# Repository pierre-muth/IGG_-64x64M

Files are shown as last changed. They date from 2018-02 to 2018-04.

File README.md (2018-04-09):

# IGG_-64x64M
Driving and use the ИГГ1/64x64M. Gazotron Dot-matrix display made in Ukraine in the 80's
Details: https://hackaday.io/project/46302-1-64x64m-adventure

Status:
High voltage (360v from 180v) driver circuit board
PIC 18F87K90 serial interface

Connected to a raspberry-pi: https://youtu.be/ZqoKS0ZieYE 





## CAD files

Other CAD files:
pic/igg_driver_test_01.X/dist/default/production/igg_driver_test_01.X.production.obj

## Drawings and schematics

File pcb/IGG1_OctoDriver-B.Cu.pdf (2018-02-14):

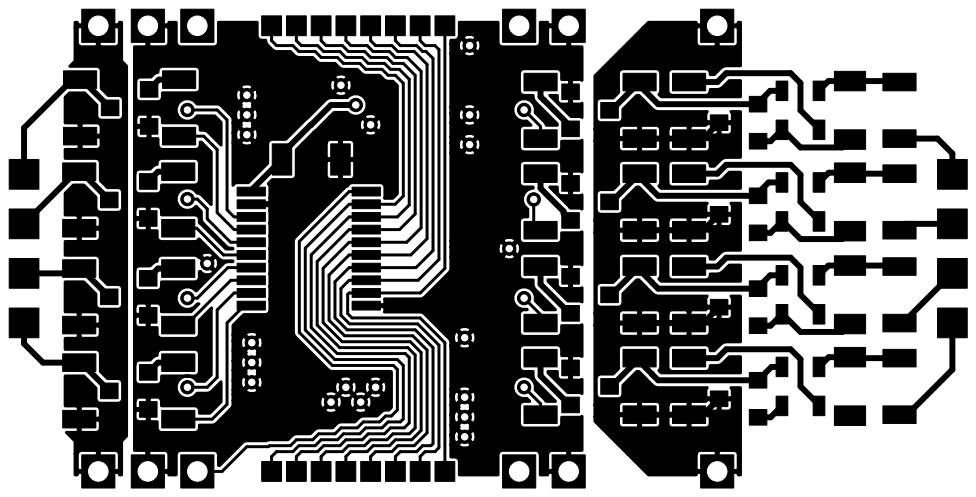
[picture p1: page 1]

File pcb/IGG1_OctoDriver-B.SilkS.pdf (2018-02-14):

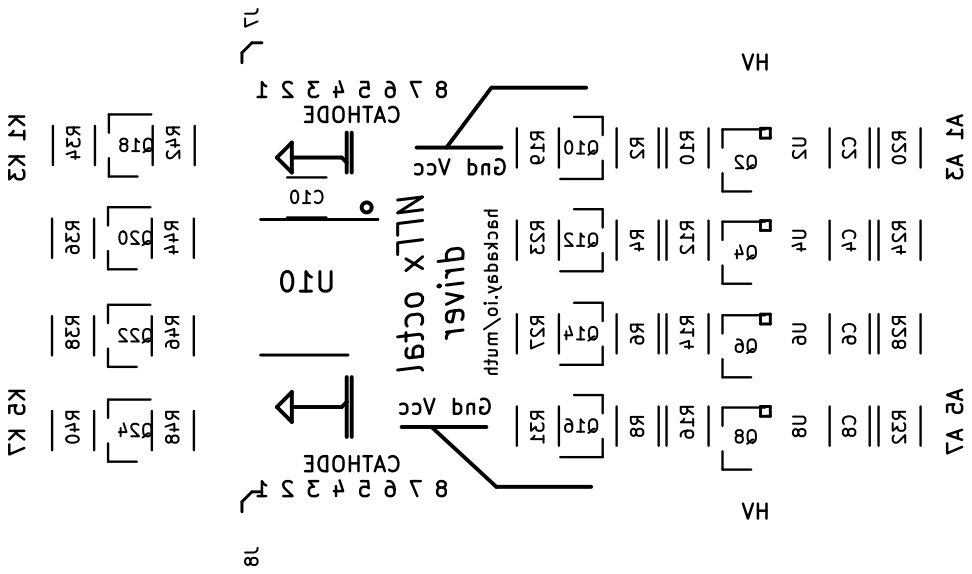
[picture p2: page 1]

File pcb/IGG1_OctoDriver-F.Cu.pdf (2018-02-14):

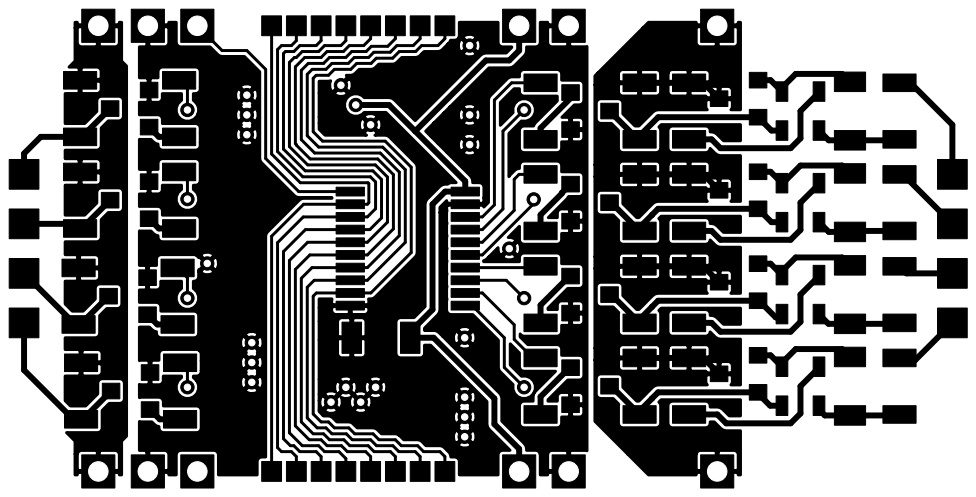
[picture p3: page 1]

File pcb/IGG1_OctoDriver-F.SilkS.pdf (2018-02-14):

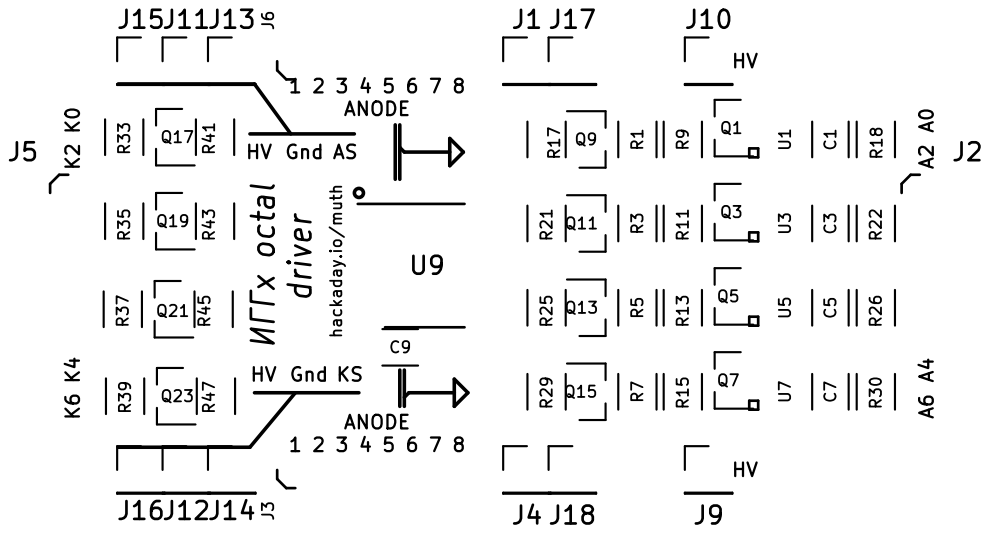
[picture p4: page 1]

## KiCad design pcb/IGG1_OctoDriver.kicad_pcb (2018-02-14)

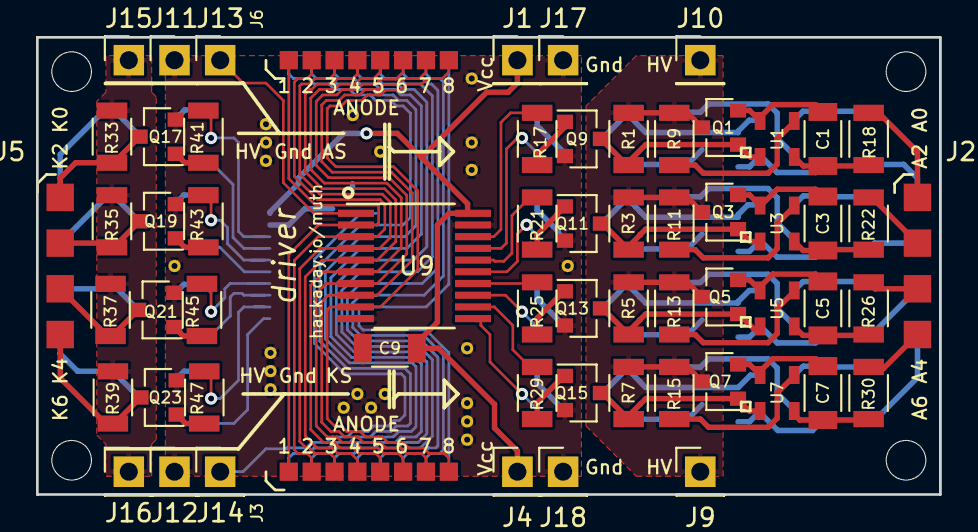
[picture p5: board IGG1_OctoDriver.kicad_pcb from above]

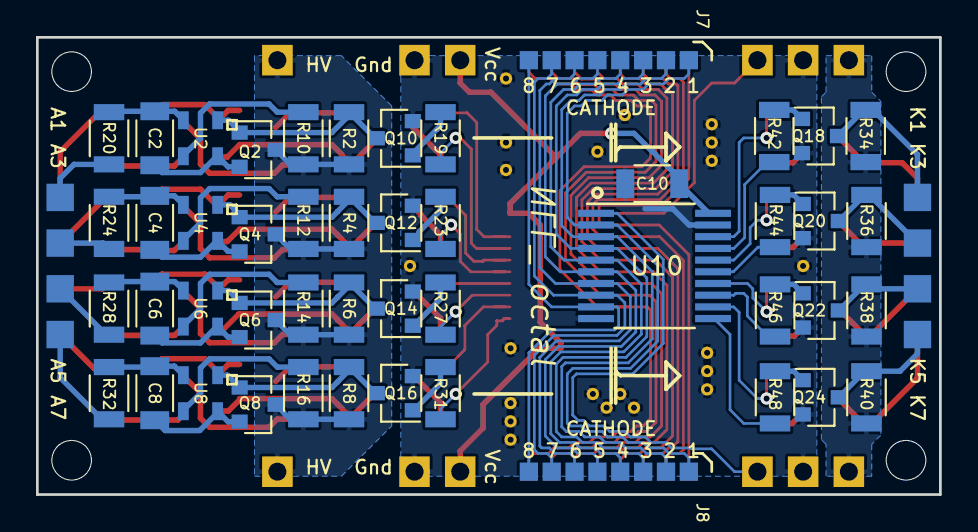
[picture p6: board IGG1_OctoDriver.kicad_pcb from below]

Board: 2 copper layers, 50.2 x 25.4 mm, 131 parts (48 on the bottom side), 101 nets.

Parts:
C1, C2, C3, C4, C5, C6, C7, C8: 1n; C_1206
C9, C10: 100n; C_1206
J1, J4, J9, J10, J11, J12, J13, J14, J15, J16, J17, J18: Conn_01x01; Pin_Header_Straight_1x01_Pitch2.54mm
J2, J5: Conn_01x08; Pin_Header_21x04_Pitch2.54mm_SMD_2sides
J3, J6, J7, J8: Conn_01x08; Pin_Header_1x08_Pitch1.27mm_SMD
J19, J19#2, J19#3, J19#4, J19#5, J19#6, J19#7, J19#8, J19#9, J19#10, J19#11, J19#12, J19#13, J19#14, J19#15, J19#16, J19#17, J19#18, J19#19, J19#20, J19#21: TEST_1P; via
Q1, Q2, Q3, Q4, Q5, Q6, Q7, Q8, Q9, Q10, Q11, Q12, Q13, Q14, Q15, Q16, Q17, Q18, Q19, Q20, Q21, Q22, Q23, Q24: Q_NPN_BEC; SOT-23
R1, R2, R3, R4, R5, R6, R7, R8, R33, R34, R35, R36, R37, R38, R39, R40: 220K; R_1206
R9, R10, R11, R12, R13, R14, R15, R16: 4.7K; R_1206
R17, R19, R21, R23, R25, R27, R29, R31, R41, R42, R43, R44, R45, R46, R47, R48: 10K; R_1206
R18, R20, R22, R24, R26, R28, R30, R32: 100K; R_1206
U1, U2, U3, U4, U5, U6, U7, U8: DiodeArray; SOT-457
U9, U10: 74LS541; TSSOP-20_4.4x6.5mm_Pitch0.65mm_handsoldering

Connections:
AI0: R17.2, U9.18
AI1: R19.2, U9.17
AI2: R21.2, U9.16
AI3: R23.2, U9.15
AI4: R25.2, U9.14
AI5: R27.2, U9.13
AI6: R29.2, U9.12
AI7: R31.2, U9.11
AO0: J2.1, R18.1
AO1: J2.2, R20.1
AO2: J2.3, R22.1
AO3: J2.4, R24.1
AO4: J2.5, R26.1
AO5: J2.6, R28.1
AO6: J2.7, R30.1
AO7: J2.8, R32.1
AS: J13.1, U9.1
GND: C9.1, C10.1, J11.1, J12.1, J17.1, J18.1, J19.1, J19#2.1, J19#3.1, J19#4.1, J19#5.1, J19#6.1, J19#7.1, J19#8.1, J19#9.1, J19#10.1, J19#11.1, J19#12.1, J19#13.1, J19#14.1, J19#15.1, J19#16.1, J19#17.1, J19#18.1, J19#19.1, J19#20.1, J19#21.1, Q9.2, Q10.2, Q11.2, Q12.2, Q13.2, Q14.2, Q15.2, Q16.2, Q17.2, Q18.2, Q19.2, Q20.2, Q21.2, Q22.2, Q23.2, Q24.2, U9.10, U9.19, U10.10, U10.19
HT: J9.1, J10.1, J15.1, J16.1, Q1.3, Q2.3, Q3.3, Q4.3, Q5.3, Q6.3, Q7.3, Q8.3, R1.1, R2.1, R3.1, R4.1, R5.1, R6.1, R7.1, R8.1, R9.1, R10.1, R11.1, R12.1, R13.1, R14.1, R15.1, R16.1, R33.1, R34.1, R35.1, R36.1, R37.1, R38.1, R39.1, R40.1
KI0: R41.2, U10.18
KI1: R42.2, U10.17
KI2: R43.2, U10.16
KI3: R44.2, U10.15
KI4: R45.2, U10.14
KI5: R46.2, U10.13
KI6: R47.2, U10.12
KI7: R48.2, U10.11
KO0: J5.1, Q17.3, R33.2
KO1: J5.2, Q18.3, R34.2
KO2: J5.3, Q19.3, R35.2
KO3: J5.4, Q20.3, R36.2
KO4: J5.5, Q21.3, R37.2
KO5: J5.6, Q22.3, R38.2
KO6: J5.7, Q23.3, R39.2
KO7: J5.8, Q24.3, R40.2
KS: J14.1, U10.1
unnamed: C1.1, R18.2, U1.3
unnamed: C1.2, Q1.2, U1.6
unnamed: C2.1, R20.2, U2.3
unnamed: C2.2, Q2.2, U2.6
unnamed: C3.1, R22.2, U3.3
unnamed: C3.2, Q3.2, U3.6
unnamed: C4.1, R24.2, U4.3
unnamed: C4.2, Q4.2, U4.6
unnamed: C5.1, R26.2, U5.3
unnamed: C5.2, Q5.2, U5.6
unnamed: C6.1, R28.2, U6.3
unnamed: C6.2, Q6.2, U6.6
unnamed: C7.1, R30.2, U7.3
unnamed: C7.2, Q7.2, U7.6
unnamed: C8.1, R32.2, U8.3
unnamed: C8.2, Q8.2, U8.6
unnamed: J3.1, J6.1, U9.2
unnamed: J3.2, J6.2, U9.3
unnamed: J3.3, J6.3, U9.4
unnamed: J3.4, J6.4, U9.5
unnamed: J3.5, J6.5, U9.6
unnamed: J3.6, J6.6, U9.7
unnamed: J3.7, J6.7, U9.8
unnamed: J3.8, J6.8, U9.9
unnamed: J7.1, J8.1, U10.2
unnamed: J7.2, J8.2, U10.3
unnamed: J7.3, J8.3, U10.4
unnamed: J7.4, J8.4, U10.5
unnamed: J7.5, J8.5, U10.6
unnamed: J7.6, J8.6, U10.7
unnamed: J7.7, J8.7, U10.8
unnamed: J7.8, J8.8, U10.9
unnamed: Q1.1, Q9.3, R1.2, U1.1
unnamed: Q9.1, R17.1
unnamed: Q10.1, R19.1
unnamed: Q2.1, Q10.3, R2.2, U2.1
unnamed: Q11.1, R21.1
unnamed: Q3.1, Q11.3, R3.2, U3.1
unnamed: Q12.1, R23.1
unnamed: Q4.1, Q12.3, R4.2, U4.1
unnamed: Q13.1, R25.1
unnamed: Q5.1, Q13.3, R5.2, U5.1
unnamed: Q14.1, R27.1
unnamed: Q6.1, Q14.3, R6.2, U6.1
unnamed: Q15.1, R29.1
unnamed: Q7.1, Q15.3, R7.2, U7.1
unnamed: Q16.1, R31.1
unnamed: Q8.1, Q16.3, R8.2, U8.1
unnamed: Q17.1, R41.1
unnamed: Q18.1, R42.1
unnamed: Q19.1, R43.1
unnamed: Q20.1, R44.1
unnamed: Q21.1, R45.1
unnamed: Q22.1, R46.1
unnamed: Q23.1, R47.1
unnamed: Q24.1, R48.1
unnamed: R9.2, U1.4
unnamed: R10.2, U2.4
unnamed: R11.2, U3.4
unnamed: R12.2, U4.4
unnamed: R13.2, U5.4
unnamed: R14.2, U6.4
unnamed: R15.2, U7.4
unnamed: R16.2, U8.4
VCC: C9.2, C10.2, J1.1, J4.1, U9.20, U10.20

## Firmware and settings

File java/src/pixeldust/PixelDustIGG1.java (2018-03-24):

package pixeldust;

import java.io.IOException;
import java.util.Timer;
import java.util.TimerTask;

import com.pi4j.io.i2c.I2CBus;
import com.pi4j.io.i2c.I2CDevice;
import com.pi4j.io.i2c.I2CFactory;
import com.pi4j.io.i2c.I2CFactory.UnsupportedBusNumberException;
import com.pi4j.io.serial.Serial;
import com.pi4j.io.serial.SerialFactory;

/**
 * Java port of the PixelDust Adafruit original code
 * Written by Phil "PaintYourDragon" Burgess for Adafruit Industries.
 * https://github.com/adafruit/Adafruit_PixelDust
 * @author Pierre Muth
 * 
 * @mainpage Particle simulation for "LED sand."
 *
 * @section intro_sec Introduction
 *
 * This handles the "physics engine" part of a sand/rain simulation.
 * The term "physics" is used loosely here...it's a relatively crude
 * algorithm that's appealing to the eye but takes many shortcuts with
 * collision detection, etc.
 *
 * @section dependencies Dependencies
 *
 * Not dependent on other libraries for compilation. HOWEVER, this code
 * does not actually render anything itself and needs to be used in
 * conjunction with a display-specific library to handle graphics.
 *
 * @section author Author
 *
 * Written by Phil "PaintYourDragon" Burgess for Adafruit Industries.
 *
 * @section license License
 *
 * BSD license, all text here must be included in any redistribution.
 *
 */

public class PixelDustIGG1 {
	public static final int WIDTH  = 64; 		// Width in pixels
	public static final int HEIGHT = 64; 		// Height in pixels
	public static final int GRAIN_NUMBER = 10*64;	// Number of sand grains
	public static final int SCALE = 256;			// Accelerometer input scaling = scale/256
	public static final int ELASTICITY = 64;	// Grain elasticity (bounce) = elasticity/256
	public static final int ZOOM = 10;	 		// for display, size of the squares representing a pixel
	
	public static final int X_MAX = WIDTH*256-1;  // Max X coordinate in grain space
	public static final int Y_MAX = HEIGHT*256-1; // Max Y coordinate in grain space
	
	public static int[][] bitmap = new int[WIDTH][HEIGHT];		// pixel bitmap
	public static Grain[] grains = new Grain[GRAIN_NUMBER];		//One per grain
	
	private Timer timer;
	private static int[] pixList = new int[HEIGHT * WIDTH];
	private static byte[] imageBytes = new byte[WIDTH * (HEIGHT/8)];
	
	private int ax = 0;
	private int ay = 0;
	
	private final Serial serial;
	private I2CDevice MPU9250device;
	
	public PixelDustIGG1() throws IOException, UnsupportedBusNumberException, InterruptedException{
		serial = SerialFactory.createInstance();

		String comPort = Serial.DEFAULT_COM_PORT;
		int serialSpeed = 115200;

		serial.open(comPort, serialSpeed);
		System.out.println("Opened "+ comPort+" at "+serialSpeed+" bauds.");
		
		final I2CBus bus = I2CFactory.getInstance(I2CBus.BUS_1);

		MPU9250device = bus.getDevice(MPU9250.ADDRESS);
		
		MPU9250device.write(MPU9250.PWR_MGMT_1, (byte) 0x00);
		Thread.sleep(100);
		MPU9250device.write(MPU9250.PWR_MGMT_1, (byte) 0x01);
		Thread.sleep(200);
		
		MPU9250device.write(MPU9250.CONFIG, (byte) 0x03);
		MPU9250device.write(MPU9250.SMPLRT_DIV, (byte) 0x04);
		
		
		MPU9250device.write(MPU9250.ACCEL_CONFIG, (byte) 0x00);
		MPU9250device.write(MPU9250.ACCEL_CONFIG2, (byte) 0x03);
		
		int read = MPU9250device.read(MPU9250.WHO_AM_I_MPU9250);
		System.out.println("WHO_AM_I_MPU9250 > "+read);
		
		for (int i = 0; i < pixList.length; i++) {
			pixList[i] = 0;
		}

		// Set the grains
		for (int i = 0; i < GRAIN_NUMBER; i++) {
			grains[i] = new Grain();
			grains[i].x = (i%64)*256;
			grains[i].y = ( 63-(i/64) ) *256;
		}
		
		// Draw adafruit logo
		for (int i = 0; i < AdaLogo.LOGO_WIDTH; i++) {
			for (int j = 0; j < AdaLogo.LOGO_HEIGHT; j++) {
				bitmap[i+12][j+12] = AdaLogo.LOGO_GRAY[i+j*AdaLogo.LOGO_WIDTH];
			}
		}
		
		// launch the simulator
		SimulateTask simulateTask = new SimulateTask();
		UpdateIGG1Task updateIGG1Task = new UpdateIGG1Task();
		UpdateAccelerationTask updateAccelerationTask = new UpdateAccelerationTask();
		timer = new Timer();
		timer.schedule(simulateTask, 2000, 16);
		timer.schedule(updateIGG1Task, 250, 100);
		timer.schedule(updateAccelerationTask, 200, 100);
		
		
	}
	
	private void iterate(int ax, int ay, int az) {
		
		ax = ax * SCALE / 256;  // Scale down raw accelerometer
		ay = ay * SCALE / 256;  // inputs to manageable range.
		az = az * SCALE / 2048; // Z is further scaled down 1:8
		// A tiny bit of random motion is applied to each grain, so that tall
		// stacks of pixels tend to topple (else the whole stack slides across
		// the display).  This is a function of the Z axis input, so it's more
		// pronounced the more the display is tilted (else the grains shift
		// around too much when the display is held level).
		az  = (az >= 4) ? 1 : 5 - az; // Clip & invert
		ax -= az;                     // Subtract Z motion factor from X, Y,
		ay -= az;                     // then...
		int az2 = az * 2 + 1;     	  // max random motion to add back in


		// Apply 2D accel vector to grain velocities...
		int v2; // Velocity squared
		double   v;  // Absolute velocity
		for(int i=0; i<grains.length; i++) {
			grains[i].vx += ax + Math.random()*az2;
			grains[i].vy += ay + Math.random()*az2;
			// Terminal velocity (in any direction) is 256 units -- equal to
			// 1 pixel -- which keeps moving grains from passing through each other
			// and other such mayhem.  Though it takes some extra math, velocity is
			// clipped as a 2D vector (not separately-limited X & Y) so that
			// diagonal movement isn't faster than horizontal/vertical.
			v2 = grains[i].vx*grains[i].vx+grains[i].vy*grains[i].vy;
			if(v2 > 65536) { // If v^2 > 65536, then v > 256
				v = Math.sqrt(v2); // Velocity vector magnitude
				grains[i].vx = (int)(256.0*(float)grains[i].vx/v); // Maintain heading &
				grains[i].vy = (int)(256.0*(float)grains[i].vy/v); // limit magnitude
			}
		}

		// ...then update position of each grain, one at a time, checking for
		// collisions and having them react.  This really seems like it shouldn't
		// work, as only one grain is considered at a time while the rest are
		// regarded as stationary.  Yet this naive algorithm, taking many not-
		// technically-quite-correct steps, and repeated quickly enough,
		// visually integrates into something that somewhat resembles physics.
		// (I'd initially tried implementing this as a bunch of concurrent and
		// "realistic" elastic collisions among circular grains, but the
		// calculations and volume of code quickly got out of hand for both
		// the tiny 8-bit AVR microcontroller and my tiny dinosaur brain.)

		for(int i=0; i<grains.length; i++) {
			int newx = grains[i].x + grains[i].vx; // New position in grain space
			int newy = grains[i].y + grains[i].vy;
			if(newx < 0) {         // If grain would go out of bounds
				newx = 0;            // keep it inside,
				grains[i].vx = bounce(grains[i].vx); // and bounce off wall
			} else if(newx > X_MAX) {
				newx = X_MAX;
				grains[i].vx = bounce(grains[i].vx);
			}
			if(newy < 0) {
				newy = 0;
				grains[i].vy = bounce(grains[i].vy);
			} else if(newy > Y_MAX) {
				newy = Y_MAX;
				grains[i].vy = bounce(grains[i].vy);
			}

			// oldidx/newidx are the prior and new pixel index for this grain.
			// It's a little easier to check motion vs handling X & Y separately.
			int oldidx = (grains[i].y / 256) * WIDTH + (grains[i].x / 256);
			int newidx = (newy       / 256) * WIDTH + (newx       / 256);

			if((oldidx != newidx) && bitmap[newx/256][newy/256] !=0) {      // If grain is moving to a new pixel but already occupied..
				int delta = Math.abs(newidx - oldidx); // What direction when blocked?
				if(delta == 1) {              // 1 pixel left or right)
					newx = grains[i].x;          // Cancel X motion
					grains[i].vx = bounce(grains[i].vx);        // and bounce X velocity (Y is OK)
				} else if(delta == WIDTH) {   // 1 pixel up or down
					newy = grains[i].y;          // Cancel Y motion
					grains[i].vy = bounce(grains[i].vy);        // and bounce Y velocity (X is OK)
				} else { // Diagonal intersection is more tricky...
					// Try skidding along just one axis of motion if possible
					// (start w/faster axis).
					if(Math.abs(grains[i].vx) >= Math.abs(grains[i].vy)) { // X axis is faster
						if(bitmap[newx / 256][grains[i].y / 256] == 0) { // newx, oldy
							// That pixel's free!  Take it!  But...
							newy = grains[i].y;      // Cancel Y motion
							grains[i].vy = bounce(grains[i].vy);    // and bounce Y velocity
						} else { // X pixel is taken, so try Y...
							if( bitmap[grains[i].x / 256][ newy / 256] == 0) { // oldx, newy
								// Pixel is free, take it, but first...
								newx = grains[i].x;    // Cancel X motion
								grains[i].vx = bounce(grains[i].vx);  // and bounce X velocity
							} else { // Both spots are occupied
								newx = grains[i].x;    // Cancel X & Y motion
								newy = grains[i].y;
								grains[i].vx = bounce(grains[i].vx);  // Bounce X & Y velocity
								grains[i].vy = bounce(grains[i].vy);
							}
						}
					} else { // Y axis is faster, start there
						if(bitmap[grains[i].x / 256][ newy / 256] == 0) { // oldx, newy
							// Pixel's free!  Take it!  But...
							newx = grains[i].x;      // Cancel X motion
							grains[i].vx = bounce(grains[i].vx);    // and bounce X velocity
						} else { // Y pixel is taken, so try X...
							if(bitmap[newx / 256][ grains[i].y / 256] == 0) { // newx, oldy
								// Pixel is free, take it, but first...
								newy = grains[i].y;    // Cancel Y motion
								grains[i].vy = bounce(grains[i].vy);  // and bounce Y velocity
							} else { // Both spots are occupied
								newx = grains[i].x;    // Cancel X & Y motion
								newy = grains[i].y;
								grains[i].vx = bounce(grains[i].vx);  // Bounce X & Y velocity
								grains[i].vy = bounce(grains[i].vy);
							}
						}
					}
				}
			}
			bitmap[grains[i].x / 256][ grains[i].y / 256] = 0; // Clear old spot
			grains[i].x = newx;                              // Update grain position
			grains[i].y = newy;
			bitmap[newx / 256][ newy / 256] = 255 ;               // Set new spot
		}
		
	}
	
	private int bounce(int n) {
		return (int) ((-n) * ELASTICITY / 256.0);	//< 1-axis elastic bounce
	}
	
	private void drawImage() {
		
		for (int i = 0; i < WIDTH; i++) {
			for (int j = 0; j < HEIGHT; j++) {
				pixList[i+j*WIDTH] = bitmap[i][j];
			}
		}
		
		byte aByte;
		byte mask;
		int bit;
		int byteOfCol;
		boolean dotState = false;
		
		for (int col = 0; col < WIDTH; col++) {
			aByte = 0x00;
			for (int row = 0; row < HEIGHT; row++) {
				
				bit = row % 8;
				mask = (byte) (0x01 << bit);
				byteOfCol = row >> 3;
			
				dotState = pixList[ (col*HEIGHT) + row ] > 32;
			
				if (dotState) {
					aByte = (byte) (aByte | (mask));
				}
				
				if (bit >=7 ){
					imageBytes[((WIDTH-1)-col)* (HEIGHT/8) + byteOfCol] = aByte;
//					System.out.println(String2Hex.byteToHex(aByte)+" ");
					aByte = 0x00;
				}
			}
//			System.out.println(".");
		}
		
		try {
			serial.write(imageBytes);
			System.out.println(".");
		} catch (IllegalStateException | IOException e) {
			e.printStackTrace();
		}
		
	}
	
	private void readAccelerometer() throws IOException {
		int x, y, z;
		x = MPU9250device.read(MPU9250.ACCEL_XOUT_H);
		y = MPU9250device.read(MPU9250.ACCEL_YOUT_H);
		z = MPU9250device.read(MPU9250.ACCEL_ZOUT_H);

		ax = -(((x+128)%256)-128);
		ay = ((y+128)%256)-128;

		System.out.println("ax: "+ax+", ay: "+ay);
	}
	
	public static void main(String[] args) throws Exception {
		PixelDustIGG1 pixelDustIGG1 = new PixelDustIGG1();
	}
	
	private class Grain {
		public int x, y;
		public int vx, vy;
	}
	
	private class SimulateTask extends TimerTask {
		
		@Override
		public void run() {
			
			PixelDustIGG1.this.iterate(PixelDustIGG1.this.ax, PixelDustIGG1.this.ay, 50);
			
		}
	}
	
	private class UpdateIGG1Task extends TimerTask {
		
		@Override
		public void run() {
			
			PixelDustIGG1.this.drawImage();
			
		}
	}
	
	private class UpdateAccelerationTask extends TimerTask {
		
		@Override
		public void run() {
			
			try {
				PixelDustIGG1.this.readAccelerometer();
			} catch (IOException e) {
				e.printStackTrace();
			}
			
		}
	}


}

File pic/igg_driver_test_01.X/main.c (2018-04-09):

/*
 * File:   main.c
 * Author: pierre muth
 *
 * Created on 17 février 2018, 13:42
 */


// PIC18F87K90 Configuration Bit Settings
// CONFIG1L
#pragma config RETEN = ON       // VREG Sleep Enable bit (Enabled)
#pragma config INTOSCSEL = HIGH // LF-INTOSC Low-power Enable bit (LF-INTOSC in High-power mode during Sleep)
#pragma config SOSCSEL = HIGH   // SOSC Power Selection and mode Configuration bits (High Power SOSC circuit selected)
#pragma config XINST = OFF       // Extended Instruction Set (Disabled)
// CONFIG1H
#pragma config FOSC = INTIO2    // Oscillator (Internal RC oscillator)
#pragma config PLLCFG = ON      // PLL x4 Enable bit (Enabled)
#pragma config FCMEN = OFF      // Fail-Safe Clock Monitor (Disabled)
#pragma config IESO = OFF       // Internal External Oscillator Switch Over Mode (Disabled)
// CONFIG2L
#pragma config PWRTEN = OFF     // Power Up Timer (Disabled)
#pragma config BOREN = SBORDIS  // Brown Out Detect (Enabled in hardware, SBOREN disabled)
#pragma config BORV = 3         // Brown-out Reset Voltage bits (1.8V)
#pragma config BORPWR = ZPBORMV // BORMV Power level (ZPBORMV instead of BORMV is selected)
// CONFIG2H
#pragma config WDTEN = OFF      // Watchdog Timer (WDT disabled in hardware; SWDTEN bit disabled)
#pragma config WDTPS = 1048576  // Watchdog Postscaler (1:1048576)
// CONFIG3L
#pragma config RTCOSC = SOSCREF // RTCC Clock Select (RTCC uses SOSC)
// CONFIG3H
#pragma config CCP2MX = PORTC   // CCP2 Mux (RC1)
#pragma config ECCPMX = PORTE   // ECCP Mux (Enhanced CCP1/3 [P1B/P1C/P3B/P3C] muxed with RE6/RE5/RE4/RE3)
#pragma config MSSPMSK = MSK7   // MSSP address masking (7 Bit address masking mode)
#pragma config MCLRE = OFF      // Master Clear Enable (MCLR Disabled, RG5 Enabled)
// CONFIG4L
#pragma config STVREN = ON      // Stack Overflow Reset (Enabled)
#pragma config BBSIZ = BB2K     // Boot Block Size (2K word Boot Block size)
// CONFIG5L
#pragma config CP0 = OFF        // Code Protect 00800-03FFF (Disabled)
#pragma config CP1 = OFF        // Code Protect 04000-07FFF (Disabled)
#pragma config CP2 = OFF        // Code Protect 08000-0BFFF (Disabled)
#pragma config CP3 = OFF        // Code Protect 0C000-0FFFF (Disabled)
#pragma config CP4 = OFF        // Code Protect 10000-13FFF (Disabled)
#pragma config CP5 = OFF        // Code Protect 14000-17FFF (Disabled)
#pragma config CP6 = OFF        // Code Protect 18000-1BFFF (Disabled)
#pragma config CP7 = OFF        // Code Protect 1C000-1FFFF (Disabled)
// CONFIG5H
#pragma config CPB = OFF        // Code Protect Boot (Disabled)
#pragma config CPD = OFF        // Data EE Read Protect (Disabled)
// CONFIG6L
#pragma config WRT0 = OFF       // Table Write Protect 00800-03FFF (Disabled)
#pragma config WRT1 = OFF       // Table Write Protect 04000-07FFF (Disabled)
#pragma config WRT2 = OFF       // Table Write Protect 08000-0BFFF (Disabled)
#pragma config WRT3 = OFF       // Table Write Protect 0C000-0FFFF (Disabled)
#pragma config WRT4 = OFF       // Table Write Protect 10000-13FFF (Disabled)
#pragma config WRT5 = OFF       // Table Write Protect 14000-17FFF (Disabled)
#pragma config WRT6 = OFF       // Table Write Protect 18000-1BFFF (Disabled)
#pragma config WRT7 = OFF       // Table Write Protect 1C000-1FFFF (Disabled)
// CONFIG6H
#pragma config WRTC = OFF       // Config. Write Protect (Disabled)
#pragma config WRTB = OFF       // Table Write Protect Boot (Disabled)
#pragma config WRTD = OFF       // Data EE Write Protect (Disabled)
// CONFIG7L
#pragma config EBRT0 = OFF      // Table Read Protect 00800-03FFF (Disabled)
#pragma config EBRT1 = OFF      // Table Read Protect 04000-07FFF (Disabled)
#pragma config EBRT2 = OFF      // Table Read Protect 08000-0BFFF (Disabled)
#pragma config EBRT3 = OFF      // Table Read Protect 0C000-0FFFF (Disabled)
#pragma config EBRT4 = OFF      // Table Read Protect 10000-13FFF (Disabled)
#pragma config EBRT5 = OFF      // Table Read Protect 14000-17FFF (Disabled)
#pragma config EBRT6 = OFF      // Table Read Protect 18000-1BFFF (Disabled)
#pragma config EBRT7 = OFF      // Table Read Protect 1C000-1FFFF (Disabled)
// CONFIG7H
#pragma config EBRTB = OFF      // Table Read Protect Boot (Disabled)

// includes
#include <xc.h>

// CPU freq
#define _XTAL_FREQ  (64000000UL)

// status
#define IDLE 0
#define UPDATING 1
#define BYPASS 3
#define LED PORTFbits.RF7
#define ANODES PORTA
#define CATHODES PORTE
#define A_SELECT PORTJ
#define K_SELECT PORTH

// proto
void init(void);
void screen_scan();

// global vars
unsigned char received_byte = 0;
unsigned char status = 0;
unsigned char write_screen = 0;
unsigned char read_screen = 0;
unsigned char page_counter = 0;
unsigned char column_counter = 0;

unsigned short screen_read_pointer = 0;
unsigned short screen_write_pointer = 0;

unsigned char screen_mem_1[512];
unsigned char screen_mem_2[512];

void interrupt isr(void) {
    if (PIR5bits.TMR4IF) {
        PIR5bits.TMR4IF = 0;
        screen_scan();
    }
}

void main(void) {
    init();

    LED = 1;
    __delay_ms(1000);
    LED = 0;
    
    while (1){
        if (PIR3bits.RC2IF) {       // serial byte received
            received_byte = RCREG2;
            PIR3bits.RC2IF = 0;
            
            screen_mem_1[screen_write_pointer] = received_byte;
            
            screen_write_pointer++;
            if (screen_write_pointer > 511) screen_write_pointer = 0;
            
            LED = !LED;
        }
    }
}

void screen_scan() {
    
    screen_read_pointer = (column_counter*8);
    
    K_SELECT = 0xFF;
    CATHODES = 0b1 << (column_counter%8);
    __delay_us(10);
    
    K_SELECT = ~(0b1 << (column_counter>>3));
    
    A_SELECT = 0b11111110;
    ANODES = screen_mem_1[screen_read_pointer+0];
    __delay_us(8);
    ANODES = 0;
    
    A_SELECT = 0b11111101;
    ANODES = screen_mem_1[screen_read_pointer+1];
    __delay_us(8);
    ANODES = 0;
    
    A_SELECT = 0b11111011;
    ANODES = screen_mem_1[screen_read_pointer+2];
    __delay_us(8);
    ANODES = 0;
    
    A_SELECT = 0b11110111;
    ANODES = screen_mem_1[screen_read_pointer+3];
    __delay_us(8);
    ANODES = 0;
    
    A_SELECT = 0b11101111;
    ANODES = screen_mem_1[screen_read_pointer+4];
    __delay_us(8);
    ANODES = 0;
    
    A_SELECT = 0b11011111;
    ANODES = screen_mem_1[screen_read_pointer+5];
    __delay_us(8);
    ANODES = 0;
    
    A_SELECT = 0b10111111;
    ANODES = screen_mem_1[screen_read_pointer+6];
    __delay_us(10);
    ANODES = 0;
    
    A_SELECT = 0b01111111;
    ANODES = screen_mem_1[screen_read_pointer+7];
    __delay_us(10);
    ANODES = 0;
    
    A_SELECT = 0b11111111;
    
    
    column_counter++;
    if (column_counter > 63) column_counter = 0;
    
}
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

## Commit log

2018-02-09 add kicad file
2018-02-14 extract driver kicad files to pcb folder
    [IGG1_OctoDriver.kicad_pcb, IGG1_OctoDriver.sch, IGG1_OctoDriver001.kicad_pcb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]
2018-03-09 Add PIC and Java code
    [igg_driver_test_01.X.production.obj]
2018-04-09 PIC driver at 60Hz
    [igg_driver_test_01.X.production.obj]
